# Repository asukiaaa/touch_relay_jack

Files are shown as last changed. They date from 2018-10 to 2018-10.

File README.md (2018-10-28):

# touch_relay_jack

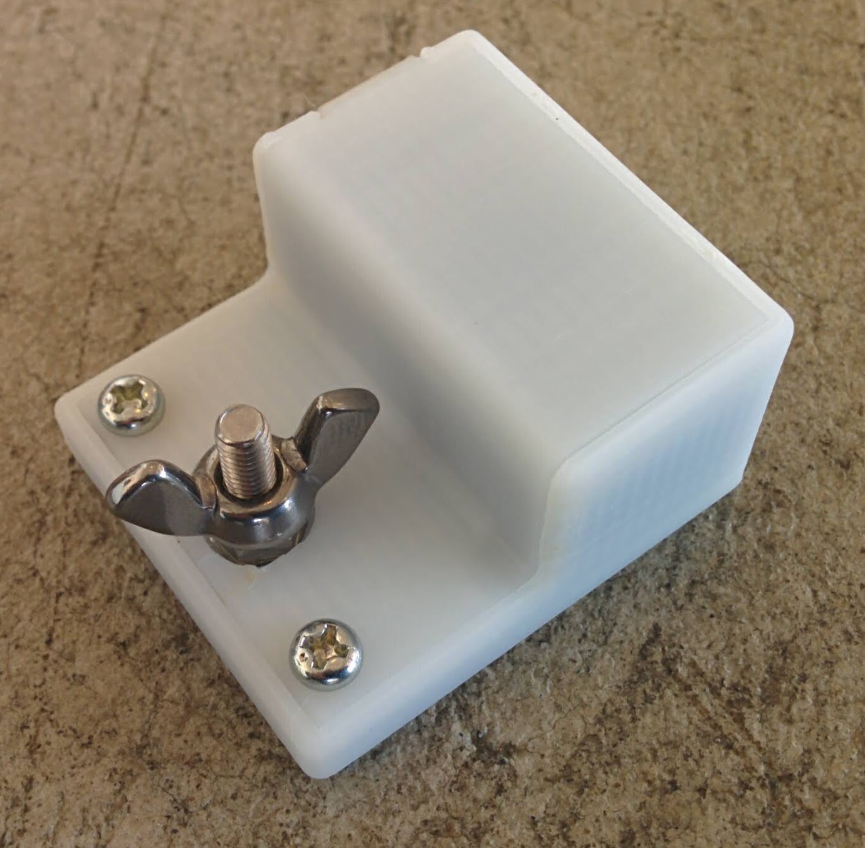
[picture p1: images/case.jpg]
case

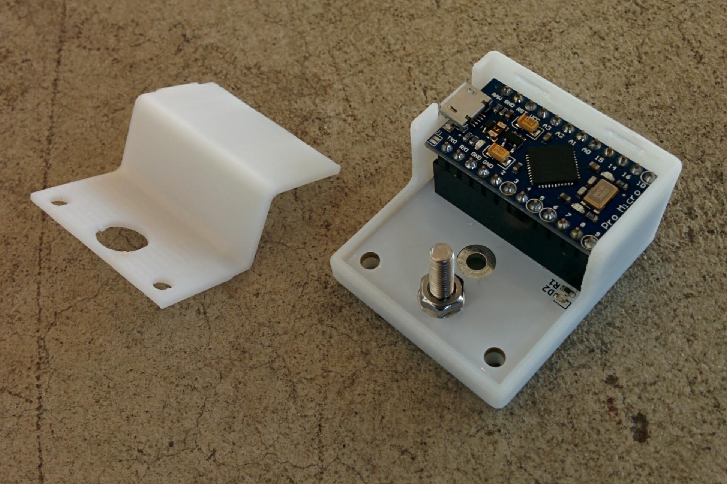
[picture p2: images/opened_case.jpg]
opened_case


Control a audio jack with using relay referencing touch sensor value.

# Pin assign

Pro Micro Pin | Role
--------- | ----
D4 | Relay
D8 | Touch signal in
D9 | Touch signal out

# Components

- [Relay](http://akizukidenshi.com/catalog/g/gP-01346/)
- [Mosfet](http://akizukidenshi.com/catalog/g/gI-04256/)
- [Diode](http://akizukidenshi.com/catalog/g/gI-06467/)
- [Resistor 1k](http://akizukidenshi.com/catalog/g/gR-06102/)
- Resistor for touch sensor: [220k](http://akizukidenshi.com/catalog/g/gR-06224/) or [1M](http://akizukidenshi.com/catalog/g/gR-06105/)
- [3.5mm audio jack](http://akizukidenshi.com/catalog/g/gC-02460/)
- [LED Green](http://akizukidenshi.com/catalog/g/gI-06417/)
- Pin Socket
- Pro Micro

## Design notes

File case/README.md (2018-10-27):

# touch_relay_jack/case

Case for touch_relay_jack.

Open and execute `case.py` on FreeCAD with using CadQuery.

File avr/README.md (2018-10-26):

# touch_relay_jack/avr

A program for Pro Micro to detect touch and control relay.

# Requirement

PlatformIO

# Upload program with using PlatformIO

```
pio run -t program
```

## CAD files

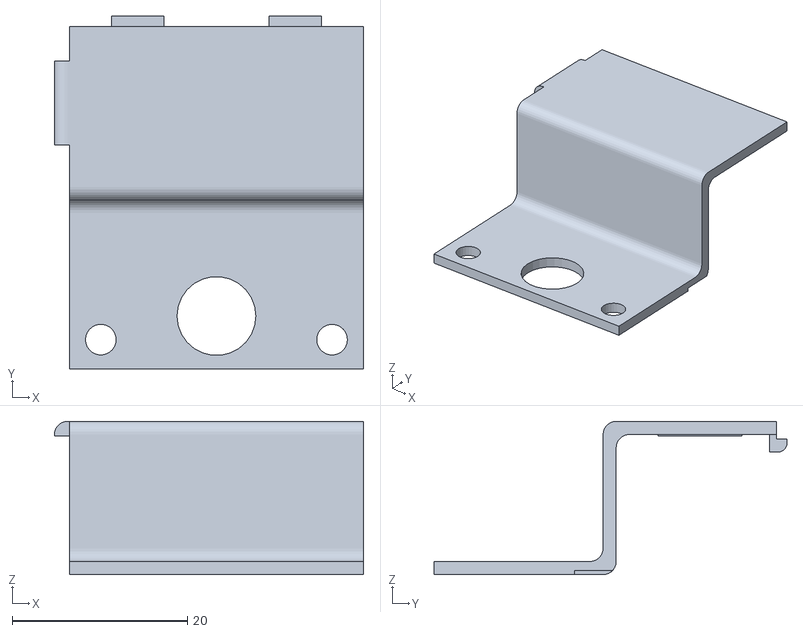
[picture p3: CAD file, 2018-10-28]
case/cover.stl
35.3 x 40.3 x 17.5

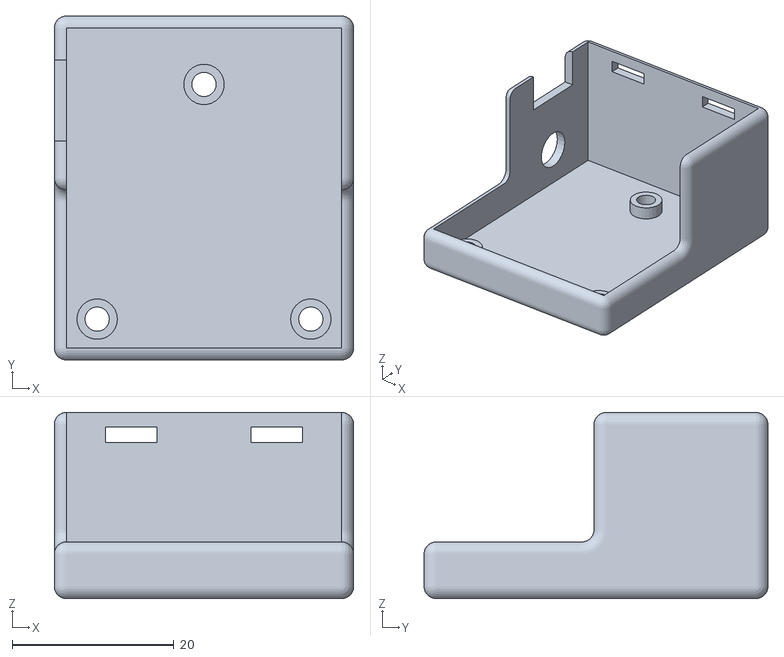
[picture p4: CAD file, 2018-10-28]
case/case.stl
37.0 x 42.5 x 23.0

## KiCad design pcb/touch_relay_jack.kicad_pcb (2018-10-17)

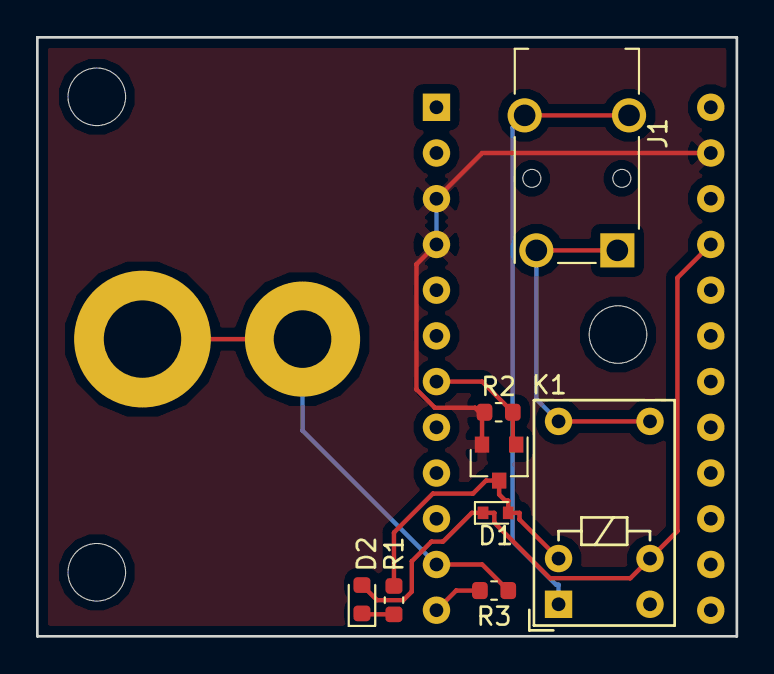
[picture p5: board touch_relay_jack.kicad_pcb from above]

Board: 2 copper layers, 38.9 x 33.3 mm, 14 parts (0 on the bottom side), 9 nets.

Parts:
A1: Pro_Micro
D1: D_Shockley; D_SOD-523
D2: LED; LED_0603_1608Metric
H1: M4Hole; MountingHole_4.3mm_M4_ISO7380_Pad
H2: M3Hole; MountingHole_3.2mm_M3_Pad
J1: AudioJack3_Ground; Jack_3.5mm_Switronic_ST-005-G_horizontal
K1: Y14x-1C-xxDS; Relay_SPDT_HsinDa_Y14
Q1: Q_NMOS_GSD; SOT-23
R1, R2: 1K; R_0603_1608Metric
R3: 1M; R_0603_1608Metric
REF1, REF2, REF3: MountingHole_3.2mm_M3

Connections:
+5V: A1.21, D1.1, D2.2, K1.4
GND: A1.3, A1.4, A1.23, Q1.2, R2.1
unnamed: A1.11, H1.1, H2.1, R3.1
unnamed: A1.12, R3.2
unnamed: D1.2, K1.3, Q1.3, R1.1
unnamed: D2.1, R1.2
unnamed: J1.R, J1.S, K1.5, K1.6
unnamed: J1.T, K1.1
Relay: A1.7, Q1.1, R2.2

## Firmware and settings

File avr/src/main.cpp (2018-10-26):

#include <Arduino.h>
#define RELAY 4
#define TOUCH_IN 8
#define TOUCH_OUT 9
#define TOUCH_THRESHOLD 1

void setup() {
  pinMode(RELAY, OUTPUT);
  pinMode(TOUCH_IN, INPUT);
  pinMode(TOUCH_OUT, OUTPUT);
  // Serial.begin(115200);
}

int count;

void loop() {
  count = 0;
  digitalWrite(TOUCH_OUT, HIGH);
  while(digitalRead(TOUCH_IN) == LOW) ++ count;
  digitalWrite(TOUCH_OUT, LOW);
  delay(100);
  // if (count != 0) Serial.println(count);
  digitalWrite(RELAY, count >= TOUCH_THRESHOLD);
}

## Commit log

2018-10-26 Create gerber files to order pcb
    [touch_relay_jack-B.Cu.gbr, touch_relay_jack-B.Mask.gbr, touch_relay_jack-B.Paste.gbr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]
2018-10-26 Add register info for touch sensor
2018-10-27 Add case and cover
    [case.stl, cover.stl]
2018-10-28 Adjust hole position and usb cover style
    [case.stl, cover.stl]
2018-10-28 Add missing support for hook
    [cover.stl]
